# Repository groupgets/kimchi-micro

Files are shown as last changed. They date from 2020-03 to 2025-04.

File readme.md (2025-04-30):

# kimχ micro

kimχ micro is a small and spicy open hardware embedded SBC that offers tons of
versitility for many different applications.

kimchi micro

## Work in progress

This board is still a work in progress and is not yet considered production-
ready. If you wish to build this hardware yourself, expect that there may still
be some bugs.

## Features

### Application Processor

This project was undertaken with video encoding/decoding and wireless
connectivity in mind, so the i.MX8M Mini variant supports 1080p60 hardware video
encode/decode.

### Mini PCIe

The board can host a half- or full-mini PCIe module as often used for high-power
wifi chipsets. Mini PCIe is also perfect for other types of wireless such as LTE
and LoRa radios.

### USB-C

The board has a full-featured USB-C port with power source and sink
capabilities, as well as support for battery charging and power.

### Expansion

To enable different applications, kimχ micro has high-density expansion
connectors and a standard add-on module specification, as well as a Qwiic
connector for rapid prototyping or simple sensor integration.

## FAQ

### How do I pronounce kimχ

Like the spicy fermented cabbage (kimchi)

### Why did you call it that

So that when we make more of these boards, we can name them things like
saurkraut, sarmale, or cole slaw, and have a series of them called the cabbage
patch. But we really do love kimchi, and it has part of KiCad in it, and i.MX.

## License

The source files for this project are licensed under CERN-OHL-S V.2. This means
you are free to reuse all or part of this design in your own projects, provided
these projects also carry the same license.

Important Note
============
GroupGets does not provide coding, firmware, or software support of any kind and will not respond to related requests. All software and firmware provided by GroupGets are offered solely as examples or potential starting points. These repositories may be outdated and are not guaranteed to function as intended.

We do not accept returns or offer replacements due to issues related to software, firmware, or code compatibility.

The software is provided "AS IS", without warranty of any kind, express or implied, including but not limited to the warranties of merchantability, fitness for a particular purpose and non-infringement. In no event shall the authors or copyright holders be liable for any claim, damages, or other liability, whether in an action of contract, tort, or otherwise, arising from, out of, or in connection with the software or the use or other dealings in the software.

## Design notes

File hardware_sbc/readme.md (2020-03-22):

# KiCAD board files for kimx micro

## Impedance requirements

```

All tolerances +/-10%.

Layers 1, 8 (kimchi_micro-F_Cu.gtl, kimchi_micro-B_Cu.gbl)
    Single ended:
        Width: 4.79 mils
        Impedance: 50 Ohms
    Differential:
        Width / Gap: 4.99 mils / 4 mils
        Impedance: 85 Ohms
    Differential:
        Width / Gap: 3.99 mils / 3.5 mils
        Impedance: 90 Ohms
    Differential:
        Width / Gap: 3.39 mils / 4.1 mils
        Impedance: 100 Ohms

Layers 2-4 (kimchi_micro-In[2-4]_Cu.g[2-4])
    Single ended:
        Width: 3.59 mils
        Impedance:  50 Ohms

```

## Stackup

```

Copper     FCu  -----                           0.33 oz, plating to 1oz
PP              xxxxx   3 mil
FR4      L2/L3  =====   0.1 mm (except copper)  1/1 oz
PP              xxxxx   9.3 mil
FR4      L4/L5  =====   0.1 mm (except copper)  1/1 oz
PP              xxxxx   9.3 mil
FR4      L6/L7  =====   0.1 mm (except copper)  1/1 oz
PP              xxxxx   3 mil
Copper     BCu  -----                           0.33 oz, plating to 1oz

Lamination thickness: 1.11 mm +/- 0.08 mm
Finished thickness: 1.2 mm

```

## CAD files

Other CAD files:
hardware_sbc/production/kimchi_micro.step

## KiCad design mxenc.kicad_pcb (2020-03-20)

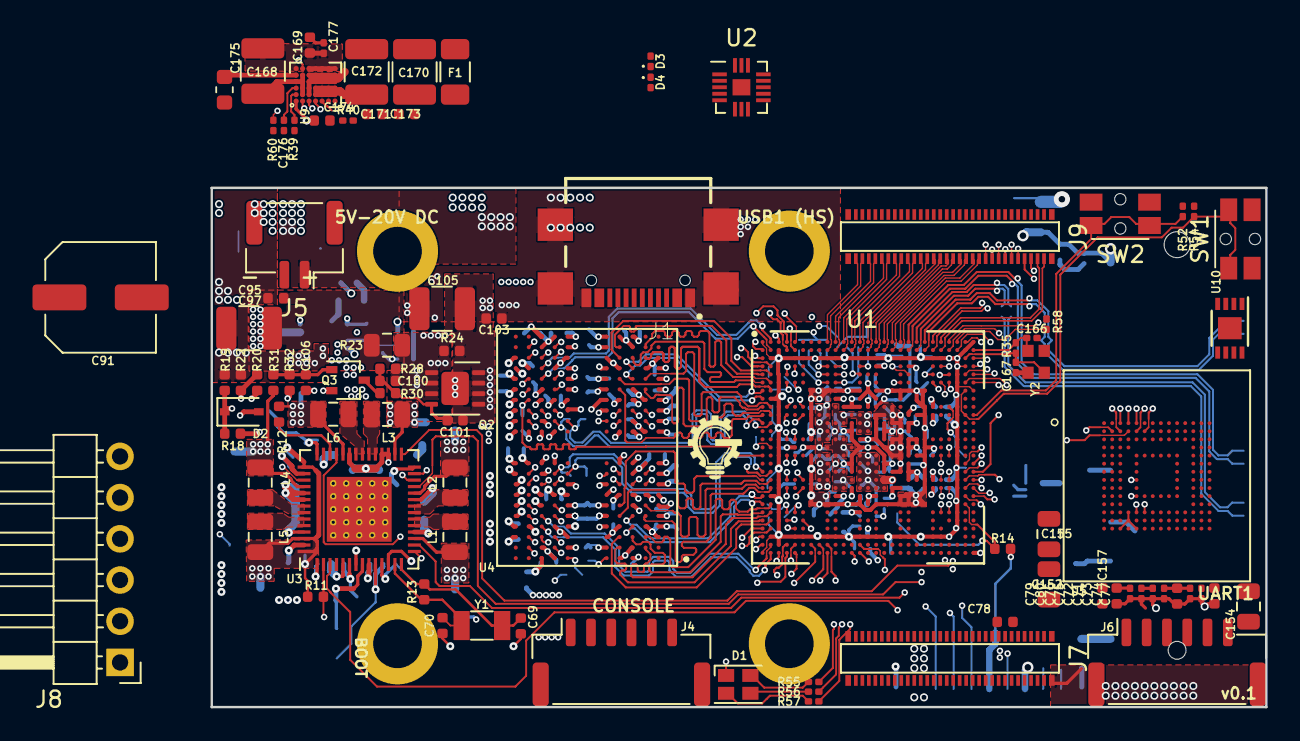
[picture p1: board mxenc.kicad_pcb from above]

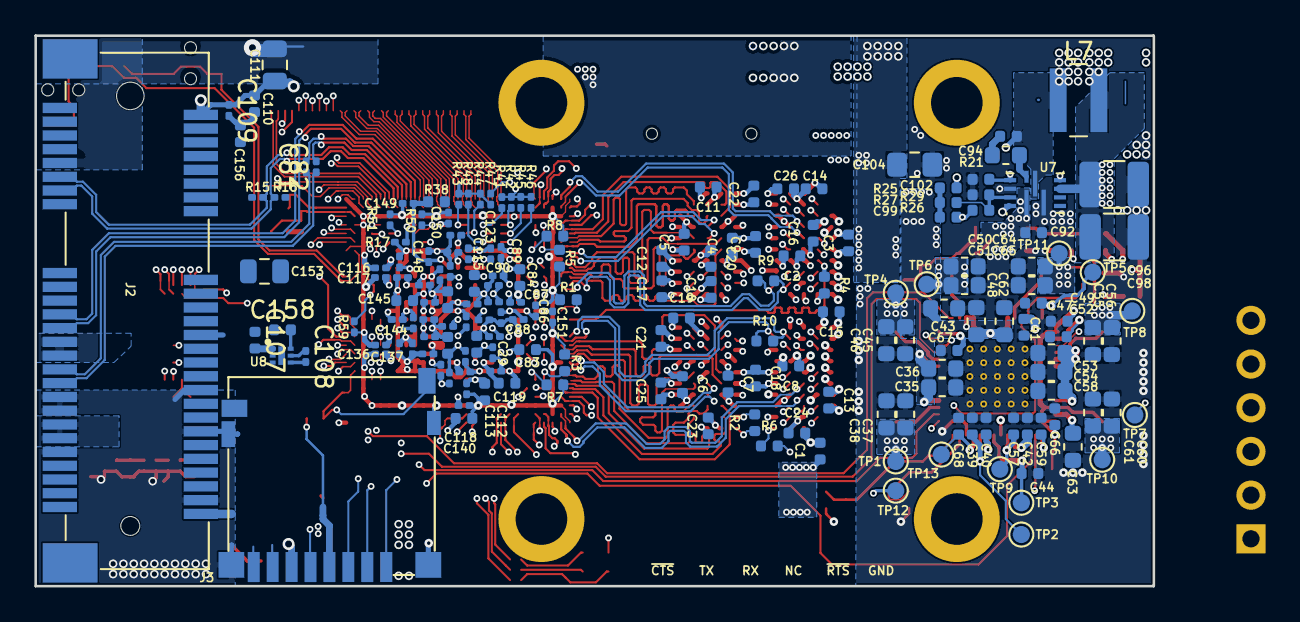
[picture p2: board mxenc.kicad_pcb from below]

Board: 8 copper layers, 65.0 x 32.0 mm, 273 parts (181 on the bottom side), 222 nets.

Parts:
C1, C2, C3, C4, C9, C10, C11, C12, C18, C19, C20, C21, C27, C28, C77, C83, C84, C112, C124, C130, C140, C157: 10uF; C_0402_1005Metric
C5, C6, C7, C8, C13, C14, C15, C16, C17, C22, C23, C24, C25, C26, C78, C94, C100, C101: 0.22uF; C_0402_1005Metric
C29, C30, C31, C32, C33, C34, C85, C86, C87, C88, C89, C90, C116, C125, C126, C127, C128, C129, C131, C132, C133, C134, C135, C151: 1uF; C_0201_0603Metric
C35, C36, C43, C48, C53, C54, C58, C62: 10uF; C_0603_1608Metric
C37, C38, C45, C46, C50, C51, C55, C56, C60, C61, C64, C65: 22uF; C_0603_1608Metric
C39, C44, C47, C52, C57, C67, C68, C79, C102, C103, C158: 1uF; C_0402_1005Metric
C40, C41, C42, C107: 2.2uF; C_0402_1005Metric
C49, C59, C66, C71, C110, C119, C145, C156: 4.7uF; C_0402_1005Metric
C63: 1uF; C_0603_1608Metric
C69, C70: 18pF; C_0402_1005Metric
C72, C73, C74, C75, C76, C80, C113, C114, C115, C117, C118, C120, C121, C122, C123, C136, C137, C138, C139, C141, C142, C143, C144, C146, C147, C148: 0.22uF; C_0201_0603Metric
C81, C82, C108, C109: 0.1uF; C_0201_0603Metric
C91: 100uF; C_Elec_6.3x5.8
C92, C95, C106, C169, C171, C173, C174: 0.1uF; C_0402_1005Metric
C96, C97, C98, C105: 100uF; C_1210_3225Metric
C99: DNP; C_0402_1005Metric
C104: 10uF; C_0805_2012Metric_Pad1.15x1.40mm_HandSolder
C111, C152, C153, C154, C155: 47uF; C_0805_2012Metric
C149: 2.2uF; C_0201_0603Metric
C150: 2200pF; C_0201_0603Metric
C166, C167: 12pF; C_0201_0603Metric
C168, C172: 47uF; C_1210_3225Metric
C170: 4.7uF; C_1210_3225Metric
C175: 4.7uF; C_0603_1608Metric
C176: 0.01uF; C_0201_0603Metric
C177: 1000pF; C_0201_0603Metric
D1: LED_ARGB; LED_Cree-PLCC4_2x2mm_CW
D2: D_Zener; D_SOD-323
D3, D4: D_TVS; D_0201_0603Metric
F1: Polyfuse; C_1206_3216Metric
J1: USB_C_Receptacle; GCT_USB4110-GF-A
J2: Bus_PCI_Express_Mini; 1775838-2-NPTH
J3: Micro_SD_Card; 114-00841-68
J4, J6: Conn_01x06; JST_GH_SM06B-GHS-TB_1x06-1MP_P1.25mm_Horizontal
J5: Conn_01x02; JST_GH_SM02B-GHS-TB_1x02-1MP_P1.25mm_Horizontal
J7, J9: DF40HC(3.5)-60DS; DF40C-60DP
J8: Conn_01x06 DNP; PinHeader_1x06_P2.54mm_Horizontal
L1, L2, L3, L5, L6: 0.47uH; L_0806
L4: 1uH; L_0806
L7: 1.5uH; L_Wuerth_MAPI-4020
L8: GG_LOGO; gg-4x4
Q2: AON7405; DFN-8-1EP_3x3mm_P0.65mm_EP1.7x2.05mm
Q3: Q_NMOS_GSD; SOT-323_SC-70
R1, R2, R6: 240; R_0402_1005Metric
R3, R5, R7, R8: 10K DNP; R_0402_1005Metric
R4, R14: 10K; R_0402_1005Metric
R9, R10: 150; R_0402_1005Metric
R11, R12, R20, R22, R32: 100K; R_0402_1005Metric
R13: 1M DNP; R_0402_1005Metric
R15, R16: 49.9; R_0201_0603Metric
R17: 8.2K; R_0201_0603Metric
R18: 1K; R_0402_1005Metric
R19, R24, R27: DNP; R_0402_1005Metric
R21: 3.3; R_0603_1608Metric
R23: 0; R_0805_2012Metric
R25: 499K DNP; R_0402_1005Metric
R26: 41.2K; R_0402_1005Metric
R28, R31: 22K; R_0402_1005Metric
R29: 5.6K; R_0402_1005Metric
R30: 4.7K; R_0402_1005Metric
R35: 510K; R_0201_0603Metric
R38: 0; R_0402_1005Metric
R39, R40, R59, R60: 100K; R_0201_0603Metric
R41, R42, R43, R44, R45, R46, R47, R48: 4.7K; R_0201_0603Metric
R50, R51: 200; R_0201_0603Metric
R52, R54, R58: 10K; R_0201_0603Metric
R55: 68; R_0201_0603Metric
R56, R57: 22; R_0201_0603Metric
SW1, SW2: SW_Push; SW_SPST_EVQP7C
TP1, TP2, TP3, TP4, TP5, TP6, TP7, TP8, TP9, TP10, TP11, TP12, TP13: TestPoint; TestPoint_Pad_D1.0mm
U1: IMX8MM; BGA-729_27x27_14.0x14.0mm
U2: PTN5110NHQZ; HX2QFN-16_EP_2.85x2.85_Pitch0.4mm
U3: BD71847MWV; QFN-56_EP_7x7_Pitch0.4mm
U4: MT53E256M32D2DS-053 WT:B; BGA200C80X65P12X22_1100X1450X80N
U5: SDINBDG4-8G; BGA153C50P14X14_1300X1150X80N
U7: MP8759GD; QFN-16_2x3_Pitch0.5mm
U8: NCP133AMX150TCG; XDFN6_1.20x1.20_0.40P
U9: NX20P3483UK; BGA-42_6x7_2.51x2.91mm
U10: 24LC16; DFN-8-1EP_3x2mm_P0.5mm_EP1.36x1.46mm
Y1: Crystal; Crystal_SMD_3215-2Pin_3.2x1.5mm
Y2: Crystal_GND24; XRCGB

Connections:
/CLK_32K: U1.A26, U3.29
/CPU Power/VDD_MIPI_1P2: C148.1, C149.1, R38.2, U1.J15
/DRAM/DRAM_CA0_A: U1.J6, U4.R2
/DRAM/DRAM_CA0_B: U1.W6, U4.H2
/DRAM/DRAM_CA1_A: U1.K6, U4.P2
/DRAM/DRAM_CA1_B: U1.V6, U4.J2
/DRAM/DRAM_CA2_A: U1.E4, U4.R9
/DRAM/DRAM_CA2_B: U1.AC4, U4.H9
/DRAM/DRAM_CA3_A: U1.D5, U4.R10
/DRAM/DRAM_CA3_B: U1.AD5, U4.H10
/DRAM/DRAM_CA4_A: U1.N4, U4.R11
/DRAM/DRAM_CA4_B: U1.R4, U4.H11
/DRAM/DRAM_CA5_A: U1.N5, U4.P11
/DRAM/DRAM_CA5_B: U1.R5, U4.J11
/DRAM/DRAM_CKE0_A: R5.1, U1.F4, U4.P4
/DRAM/DRAM_CKE0_B: R3.1, U1.AB4, U4.J4
/DRAM/DRAM_CKE1_A: R8.1, U1.F5, U4.P5
/DRAM/DRAM_CKE1_B: R7.1, U1.AB5, U4.J5
/DRAM/DRAM_CK_A_N: R9.2, U1.L1, U4.P9
/DRAM/DRAM_CK_A_P: R9.1, U1.L2, U4.P8
/DRAM/DRAM_CK_B_N: R10.2, U1.U1, U4.J9
/DRAM/DRAM_CK_B_P: R10.1, U1.U2, U4.J8
/DRAM/DRAM_CS0_A: U1.K4, U4.R4
/DRAM/DRAM_CS0_B: U1.V4, U4.H4
/DRAM/DRAM_CS1_A: U1.J4, U4.R3
/DRAM/DRAM_CS1_B: U1.W4, U4.H3
/DRAM/DRAM_DATA0_A: U1.A5, U4.AA11
/DRAM/DRAM_DATA0_B: U1.AB2, U4.B2
/DRAM/DRAM_DATA1_A: U1.B5, U4.Y11
/DRAM/DRAM_DATA1_B: U1.AA2, U4.C2
/DRAM/DRAM_DATA2_A: U1.D2, U4.V11
/DRAM/DRAM_DATA2_B: U1.W1, U4.F2
/DRAM/DRAM_DATA3_A: U1.D1, U4.U11
/DRAM/DRAM_DATA3_B: U1.W2, U4.E2
/DRAM/DRAM_DATA4_A: U1.C1, U4.U9
/DRAM/DRAM_DATA4_B: U1.V2, U4.E4
/DRAM/DRAM_DATA5_A: U1.B1, U4.V9
/DRAM/DRAM_DATA5_B: U1.V1, U4.F4
/DRAM/DRAM_DATA6_A: U1.A3, U4.Y9
/DRAM/DRAM_DATA6_B: U1.AC1, U4.B4
/DRAM/DRAM_DATA7_A: U1.B4, U4.AA9
/DRAM/DRAM_DATA7_B: U1.AC2, U4.C4
/DRAM/DRAM_DATA8_A: U1.F2, U4.AA2
/DRAM/DRAM_DATA8_B: U1.AG5, U4.B11
/DRAM/DRAM_DATA9_A: U1.G2, U4.Y2
/DRAM/DRAM_DATA9_B: U1.AF5, U4.C11
/DRAM/DRAM_DATA10_A: U1.J1, U4.V4
/DRAM/DRAM_DATA10_B: U1.AD2, U4.E11
/DRAM/DRAM_DATA11_A: U1.J2, U4.V2
/DRAM/DRAM_DATA11_B: U1.AD1, U4.F11
/DRAM/DRAM_DATA12_A: U1.K2, U4.U2
/DRAM/DRAM_DATA12_B: U1.AE1, U4.F9
/DRAM/DRAM_DATA13_A: U1.K1, U4.U4
/DRAM/DRAM_DATA13_B: U1.AF1, U4.E9
/DRAM/DRAM_DATA14_A: U1.E1, U4.AA4
/DRAM/DRAM_DATA14_B: U1.AG3, U4.C9
/DRAM/DRAM_DATA15_A: U1.E2, U4.Y4
/DRAM/DRAM_DATA15_B: U1.AF4, U4.B9
/DRAM/DRAM_DMI0_A: U1.A4, U4.Y10
/DRAM/DRAM_DMI0_B: U1.AB1, U4.C3
/DRAM/DRAM_DMI1_A: U1.F1, U4.Y3
/DRAM/DRAM_DMI1_B: U1.AG4, U4.C10
/DRAM/DRAM_NRESET: R4.1, U1.R1, U4.T11
/DRAM/DRAM_SDQS0_A_N: U1.B2, U4.V10
/DRAM/DRAM_SDQS0_A_P: U1.A2, U4.W10
/DRAM/DRAM_SDQS0_B_N: U1.Y1, U4.E3
/DRAM/DRAM_SDQS0_B_P: U1.AA1, U4.D3
/DRAM/DRAM_SDQS1_A_N: U1.H1, U4.V3
/DRAM/DRAM_SDQS1_A_P: U1.G1, U4.W3
/DRAM/DRAM_SDQS1_B_N: U1.AF2, U4.E10
/DRAM/DRAM_SDQS1_B_P: U1.AG2, U4.D10
/DRAM/DRAM_ZQ0: R2.1, U4.A5
/DRAM/DRAM_ZQ1: R6.1, U4.A8
/Expansion/CAM_CK_N: J9.45, U1.A16
/Expansion/CAM_CK_P: J9.46, U1.B16
/Expansion/CAM_D0_N: J9.41, U1.A14
/Expansion/CAM_D0_P: J9.42, U1.B14
/Expansion/CAM_D1_N: J9.43, U1.A15
/Expansion/CAM_D1_P: J9.44, U1.B15
/Expansion/CAM_D2_N: J9.47, U1.A17
/Expansion/CAM_D2_P: J9.48, U1.B17
/Expansion/CAM_D3_N: J9.49, U1.A18
/Expansion/CAM_D3_P: J9.50, U1.B18
/Expansion/DISP_CK_N: J9.35, U1.A11
/Expansion/DISP_CK_P: J9.36, U1.B11
/Expansion/DISP_D0_N: J9.31, U1.A9
/Expansion/DISP_D0_P: J9.32, U1.B9
/Expansion/DISP_D1_N: J9.33, U1.A10
/Expansion/DISP_D1_P: J9.34, U1.B10
/Expansion/DISP_D2_N: J9.37, U1.A12
/Expansion/DISP_D2_P: J9.38, U1.B12
/Expansion/DISP_D3_N: J9.39, U1.A13
/Expansion/DISP_D3_P: J9.40, U1.B13
/I2C1_SCL: R45.2, U1.E9, U3.26
/I2C1_SDA: R46.2, U1.F9, U3.27
/I2C2_SCL: R41.2, U1.D10, U10.6
/I2C2_SDA: R42.2, U1.D9, U10.5
/I2C3_SCL: J2.30, R47.2, U1.E10, U9.B1
/I2C3_SDA: J2.32, R48.2, U1.F10, U9.C1
/I2C4_SCL: R43.2, U1.D13
/I2C4_SDA: R44.2, U1.E13
/LD1_~INT: U1.F18, U9.D1
/LED_B: R57.1, U1.AF9
/LED_G: R56.1, U1.AG9
/LED_R: R55.1, U1.AF8
/PCIE_DISB: J2.20, U1.AG16
/PCIE_RSTB: J2.22, U1.AF16
/PCIe/PCIE_CLK_N: J2.11, R15.2, U1.A21
/PCIe/PCIE_CLK_P: J2.13, R16.2, U1.B21
/PCIe/PCIE_RXN_N: J2.23, U1.A19
/PCIe/PCIE_RXN_P: J2.25, U1.B19
/PCIe/PCIE_TXN_1_N: C81.2, U1.A20
/PCIe/PCIE_TXN_1_P: C82.2, U1.B20
/PCIe/PCIE_TXN_N: C81.1, J2.31
/PCIe/PCIE_TXN_P: C82.1, J2.33
/PMIC_ON_REQ: U1.A24, U3.15
/PMIC_STBY_REQ: U1.E24, U3.16
/PMIC_nINT: U1.AF13, U3.39
/POR_B: U1.B24, U3.25
/Power/BST: R21.2, U7.8
/Power/DCDC_5V_OUT: C95.1, C96.1, C97.1, C98.1, C99.1, L7.2, R23.2, R26.2, U7.5
/Power/EN: D2.1, R18.2, R19.1, U7.12
/Power/FB: R26.1, R27.2, R29.2, U7.11
/Power/MODE: R20.1, R22.1, U7.6
/Power/SW: C94.2, L7.1, R25.2, U7.7
/Power/VCC_3V6: C102.1, R20.2, U7.9
/RTC_RESET_B: U1.F24, U3.3
/SD2_VSEL: U1.AG12, U3.45
/SD/MMC/EMMC_CLK: U1.V26, U5.M6
/SD/MMC/EMMC_CMD: U1.V27, U5.M5
/SD/MMC/EMMC_DAT0: U1.Y27, U5.A3
/SD/MMC/EMMC_DAT1: U1.Y26, U5.A4
/SD/MMC/EMMC_DAT2: U1.T27, U5.A5
/SD/MMC/EMMC_DAT3: U1.T26, U5.B2
/SD/MMC/EMMC_DAT4: U1.U27, U5.B3
/SD/MMC/EMMC_DAT5: U1.U26, U5.B4
/SD/MMC/EMMC_DAT6: U1.W27, U5.B5
/SD/MMC/EMMC_DAT7: U1.W26, U5.B6
/SD/MMC/EMMC_RCLK: U1.R24, U5.H5
/SD/MMC/EMMC_RST: U1.R23, U5.K5
/SD/MMC/EMMC_VDDI: C79.1, C80.1, U5.C2
/SD/MMC/SD_CD: J3.10, R14.1, U1.AA26
/SD/MMC/SD_CLK: J3.5, U1.W23
/SD/MMC/SD_CMD: J3.3, U1.W24
/SD/MMC/SD_DAT0: J3.7, U1.AB23
/SD/MMC/SD_DAT1: J3.8, U1.AB24
/SD/MMC/SD_DAT2: J3.1, U1.V24
/SD/MMC/SD_DAT3: J3.2, U1.V23
/SYS_NRST: R12.1, U3.40
/UART1_CTS_B: J6.4, U1.AD23
/UART1_RTS_B: J6.5, U1.AC24
/UART1_RX: J6.2, U1.AB22
/UART1_TX: J6.3, U1.AC19
/UART2_CTS_B: J4.4, J8.6
/UART2_RTS_B: J4.5, J8.2
/UART2_RX: J4.2, J8.4, U1.F15
/UART2_TX: J4.3, J8.5, U1.E15
/USB/USB1_DN: D4.1, J1.A7, J1.B7, U1.A22
/USB/USB1_DP: D3.1, J1.A6, J1.B6, U1.B22
/USB/USB1_VBUS: F1.1, J1.A4, J1.A9, U1.F22
/USB/USB1_VBUS_F: C170.1, C171.1, F1.2, U9.C2, U9.C3, U9.C4, U9.C5, U9.D4, U9.D5, U9.E4, U9.E5, U9.F4, U9.F5, U9.G4, U9.G5
/VBUS_IN: C91.1, C92.1, C168.1, C169.1, C177.1, J5.1, R18.1, U7.1, U9.A6, U9.C6, U9.D6, U9.E6, U9.F6, U9.G6
/WDOG_B: R11.1, U1.AG13, U3.2
GND: C1.2, C2.2, C3.2, C4.2, C5.2, C6.2, C7.2, C8.2, C9.2, C10.2, C11.2, C12.2, C13.2, C14.2, C15.2, C16.2, C17.2, C18.2, C19.2, C20.2, C21.2, C22.2, C23.2, C24.2, C25.2, C26.2, C27.2, C28.2, C29.2, C30.2, C31.2, C32.2, C33.2, C34.2, C35.2, C36.2, C37.1, C38.1, C39.1, C40.2, C41.2, C42.2, C43.2, C44.1, C45.1, C46.1, C47.1, C48.2, C49.1, C50.1, C51.1, C52.1, C53.2, C54.2, C55.1, C56.1, C57.1, C58.2, C59.1, C60.1, C61.1, C62.2, C63.1, C64.1, C65.1, C66.1, C67.1, C68.2, C69.1, C70.1, C71.2, C72.2, C73.2, C74.2, C75.2, C76.2, C77.2, C78.2, C79.2, C80.2, C83.2, C84.2, C85.2, C86.2, C87.2, C88.2, C89.2, C90.2, C91.2, C92.2, C95.2, C96.2, C97.2, C98.2, C102.2, C103.2, C104.2, C105.2, C106.2, C107.1, C108.1, C109.2, C110.2, C111.2, C112.2, C113.2, C114.2, C115.2, C116.1, C117.1, C118.1, C119.2, C120.2, C121.2, C122.2, C123.2, C124.2, C125.2, C126.2, C127.2, C128.2, C129.2, C130.2, C131.2, C132.2, C133.2, C134.2, C135.2, C136.2, C137.2, C138.2, C139.2, C140.2, C141.2, C142.2, C143.2, C144.2, C145.2, C146.2, C147.2, C148.2, C149.2, C150.2, C151.2, C152.2, C153.2, C154.2, C155.2, C156.2, C157.2, C158.1, C166.2, C167.2, C168.2, C169.2, C170.2, C171.2, C172.2, C173.2, C174.2, C175.2, C176.2, C177.2, D2.2, D3.2, D4.2, J1.A1, J1.A12, J1.S1, J2.4, J2.9, J2.15, J2.18, J2.21, J2.26, J2.27, J2.29, J2.34, J2.35, J2.37, J2.40, J2.43, J2.50, J3.6, J3.9, J3.11, J4.6, J5.2, J6.6, J7.MP, J8.1, J9.MP, Q3.2, R1.2, R3.2, R4.2, R5.2, R7.2, R8.2, R15.1, R16.1, R17.2, R19.2, R22.2, R29.1, R32.1, R39.2, R40.2, R50.2, R51.2, R52.1, R54.1, R59.2, R60.2, U1.A1, U1.A27, U1.AA7, U1.AA9, U1.AA10, U1.AA13, U1.AA15, U1.AA18, U1.AA19, U1.AA21, U1.AB3, U1.AB25, U1.AC3, U1.AC25, U1.AE2, U1.AE5, U1.AE6, U1.AE9, U1.AE10, U1.AE13, U1.AE14, U1.AE15, U1.AE18, U1.AE19, U1.AE22, U1.AE23, U1.AF3, U1.AG1, U1.AG27, U1.B3, U1.B26, U1.C2, U1.C5, U1.C6, U1.C9, U1.C10, U1.C13, U1.C14, U1.C15, U1.C18, U1.C19, U1.C22, U1.C23, U1.D26, U1.E3, U1.E25, U1.F3, U1.F25, U1.G7, U1.G9, U1.G10, U1.G13, U1.G15, U1.G18, U1.G19, U1.G21, U1.G27, U1.H2, U1.H18, U1.J3, U1.J7, U1.J21, U1.J25, U1.K3, U1.K7, U1.K20, U1.K21, U1.K25, U1.L12, U1.L16, U1.M12, U1.M16, U1.N3, U1.N7, U1.N12, U1.N16, U1.N21, U1.N25, U1.P3, U1.P13, U1.P15, U1.P21, U1.P25, U1.R3, U1.R7, U1.R12, U1.R16, U1.R20, U1.R21, U1.R25, U1.T12, U1.T16, U1.U12, U1.U16, U1.V3, U1.V7, U1.V21, U1.V25, U1.W3, U1.W7, U1.W21, U1.W25, U1.Y2, U1.Y13, U1.Y18, U3.12, U3.57, U4.A3, U4.A10, U4.AB3, U4.AB5, U4.AB8, U4.AB10, U4.C1, U4.C5, U4.C8, U4.C12, U4.D2, U4.D4, U4.D9, U4.D11, U4.E1, U4.E5, U4.E8, U4.E12, U4.G1, U4.G3, U4.G5, U4.G8, U4.G10, U4.G12, U4.J1, U4.J3, U4.J10, U4.J12, U4.K2, U4.K4, U4.K9, U4.K11, U4.N2, U4.N4, U4.N9, U4.N11, U4.P1, U4.P3, U4.P10, U4.P12, U4.T1, U4.T3, U4.T5, U4.T8, U4.T10, U4.T12, U4.V1, U4.V5, U4.V8, U4.V12, U4.W2, U4.W4, U4.W9, U4.W11, U4.Y1, U4.Y5, U4.Y8, U4.Y12, U5.A6, U5.C4, U5.E7, U5.G5, U5.H10, U5.J5, U5.K8, U5.N2, U5.N5, U5.P4, U5.P6, U7.2, U7.10, U8.5, U8.7, U9.A4, U9.B2, U9.B3, U9.B4, U9.B5, U10.4, U10.7, Y2.2, Y2.4
GPIO3[5]: R52.2, SW2.1, U1.K27
GPIO3[12]: R54.2, SW1.1, U1.G26, U1.K26
JTAG_MOD: J9.51, U1.D27
JTAG_TCK: J9.56, U1.F26
JTAG_TDI: J9.54, U1.E27
JTAG_TDO: J9.53, U1.E26
JTAG_TMS: J9.55, U1.F27
JTAG_TRST_B: J9.52, U1.C27
NVCC_1V8: C1.1, C2.1, C3.1, C4.1, C5.1, C6.1, C7.1, C8.1, C49.2, C60.2, C61.2, C66.2, C74.1, C75.1, C76.1, C77.1, C112.1, C113.1, C114.1, C115.1, C136.1, C138.1, C139.1, C158.2, L5.2, R11.2, R41.1, R42.1, R45.1, R46.1, SW1.2, SW2.2, TP10.1, U1.AB13, U1.J11, U1.J12, U1.J13, U1.L19, U1.M19, U1.T19, U1.U19, U1.V19, U1.V20, U1.W12, U1.W22, U3.43, U3.54, U3.56, U4.F1, U4.F12, U4.G4, U4.G9, U4.T4, U4.T9, U4.U1, U4.U12, U5.C6, U5.M4, U5.N4, U5.P3, U5.P5, U8.3, U8.6, U10.8
NVCC_3V3: C55.2, C56.2, C59.2, C71.1, C72.1, C73.1, C108.2, C109.1, C110.1, C111.1, C119.1, C120.1, C121.1, C122.1, C123.1, C152.1, C153.1, C154.1, C155.1, C174.1, D1.1, J2.2, J2.24, J2.39, J2.41, J2.52, L4.2, R31.1, R43.1, R44.1, R47.1, R48.1, TP8.1, U1.H10, U1.K19, U1.W17, U1.W18, U1.Y10, U3.1, U3.7, U3.46, U5.E6, U5.F5, U5.J10, U5.K9, U8.4, U9.A1
NVCC_DRAM_1V1: C9.1, C10.1, C11.1, C12.1, C13.1, C14.1, C15.1, C16.1, C17.1, C18.1, C19.1, C20.1, C21.1, C22.1, C23.1, C24.1, C25.1, C26.1, C64.2, C65.2, C83.1, C84.1, C85.1, C86.1, C87.1, C88.1, C89.1, C90.1, L6.2, R2.2, R6.2, R12.2, TP11.1, U1.K8, U1.K9, U1.L9, U1.M9, U1.N8, U1.N9, U1.P7, U1.R8, U1.R9, U1.T9, U1.U9, U1.V8, U1.V9, U3.38, U4.A4, U4.A9, U4.AA3, U4.AA5, U4.AA8, U4.AA10, U4.AB4, U4.AB9, U4.B3, U4.B5, U4.B8, U4.B10, U4.D1, U4.D5, U4.D8, U4.D12, U4.F3, U4.F5, U4.F8, U4.F10, U4.G2, U4.H1, U4.H5, U4.H8, U4.H12, U4.K1, U4.K3, U4.K10, U4.K12, U4.N1, U4.N3, U4.N10, U4.N12, U4.R1, U4.R5, U4.R8, U4.R12, U4.T2, U4.U3, U4.U5, U4.U8, U4.U10, U4.W1, U4.W5, U4.W8, U4.W12
NVCC_SD2: C63.2, C78.1, C137.1, J3.4, R14.2, TP12.1, U1.V22, U3.55
NVCC_SNVS_1V8: C39.2, C67.2, C116.2, R58.2, TP2.1, U1.J22, U3.10, U3.28
unnamed: C68.1, TP13.1, U3.11
unnamed: C69.2, R13.2, U3.14, Y1.1
unnamed: C70.2, R13.1, U3.13, Y1.2
unnamed: C94.1, R21.1
unnamed: C99.2, R25.1, R27.1
unnamed: C100.1, C101.2, Q2.4, R28.1, R30.2
unnamed: C106.1, Q3.1, R31.2, R32.2
unnamed: C150.1, U1.D15
unnamed: C166.1, R35.2, U1.B27, Y2.1
unnamed: C167.1, R35.1, U1.C26, Y2.3
unnamed: C175.1, U9.A5
unnamed: C176.1, U9.A3
unnamed: D1.2, R55.2
unnamed: D1.3, R56.2
unnamed: D1.4, R57.2
unnamed: L1.1, U3.19, U3.20
unnamed: L2.1, U3.21, U3.22
unnamed: L3.1, U3.33, U3.34
unnamed: L4.1, U3.49, U3.50
unnamed: L5.1, U3.51, U3.52
unnamed: L6.1, U3.35, U3.36
unnamed: Q3.3, R30.1
unnamed: R1.1, U1.P2
unnamed: R17.1, U1.D19
unnamed: R39.1, U9.A2
unnamed: R40.1, U9.E1
unnamed: R50.1, U1.E19
unnamed: R51.1, U1.E22
unnamed: R58.1, U1.A25
unnamed: R59.1, U1.J24
unnamed: R60.1, U9.B6
USB2_DN: J9.59, U1.A23
USB2_DP: J9.60, U1.B23
USB2_ID: J9.58, U1.D23
USB2_VBUS: J9.57, U1.F23
VDDA_1V8: C57.2, C118.2, C140.1, C141.1, C142.1, C143.1, C144.1, C151.1, TP9.1, U1.AA14, U1.G14, U1.H13, U1.H15, U1.N19, U1.N20, U1.P5, U1.P19, U1.R19, U1.Y15, U3.6
VDD_5V: C101.1, C103.1, C104.1, C105.1, C172.1, C173.1, J4.1, J6.1, Q2.5, Q2.6, Q2.7, Q2.8, Q2.9, R24.1, U9.D2, U9.D3, U9.E2, U9.E3, U9.F2, U9.F3, U9.G2, U9.G3
VDD_ARM_0V9: C45.2, C46.2, C124.1, C125.1, C126.1, C127.1, C128.1, C129.1, L2.2, TP4.1, U1.R13, U1.R15, U1.T13, U1.T14, U1.T15, U1.U13, U1.U15, U1.V13, U1.V15, U1.V16, U1.W13, U1.W14, U1.W15, U1.W16, U3.24
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

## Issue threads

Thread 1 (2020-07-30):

v0.9 errata

kekiefer, 2020-07-30:
This issue will be updated for any hardware bugs found in development of v0.9 board

* Problem: 1.8v-capable SDHC (UHS-I and newer) cards won't work in Linux
    Root cause: microsd SD2 powered by NVCC_SD2, but needs a constant 3.3V
    Workaround (software): add device tree property `no-1-8-v`
    Proposed v1.0 solution: supply microsd SD2 VDD with VDD_3V3

* Problem: voltage sag on initial power causes pmic to shut down
    Root cause: excessive inrush current on VDD_3V3 due to aggressive decoupling for PCIe
    Workaround (hardware): don't stuff C125-127. Change reflected in released v0.9 BOM.
    Proposed v1.0 solution: add load switch with inrush-limiting for PCIe 3.3V rail

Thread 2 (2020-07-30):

1.8v-capable SDHC (UHS-I and newer) cards won't work in Linux

kekiefer, 2020-07-30:
The switch to 1.8V operation for UHS-I mode is undervolting most cards, causing errors in operation.

J10 VDD should be supplied by VDD_3V3.

Closed 2020-07-30.

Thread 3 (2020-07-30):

voltage sag on initial power causes pmic to shut down

kekiefer, 2020-07-30:
Excessive inrush current due to aggressive decoupling on PCIe 3V3 is causing this voltage sag.

Removing these extra decoupling caps allows the pmic to power up properly.

kekiefer, 2020-07-30:
Fixed in 898216086c9d1b7934d0dd7573267c3b1b6184aa (BOM update)

Closed 2020-07-30.

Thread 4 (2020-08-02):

Type-C port will not take host role

kekiefer, 2020-08-02:
Type-C port controller PTN5110 (U9) not showing up in i2cdetect. This part should be located at 0x50 on i2c3, but does not show up in a scan:

```
root@kimchi:~# i2cdetect -y 3
     0  1  2  3  4  5  6  7  8  9  a  b  c  d  e  f
00:          -- -- -- -- -- -- -- -- -- -- -- -- --
10: -- -- -- -- -- -- -- -- -- -- -- -- -- -- -- --
20: -- -- -- -- -- -- -- -- -- -- -- -- UU -- -- --
30: -- -- -- -- -- -- -- -- -- -- -- -- -- -- -- --
40: -- -- -- -- -- -- -- -- -- -- -- -- -- -- -- --
50: -- -- -- -- -- -- -- 57 -- -- -- -- -- -- -- --
60: -- -- -- -- -- -- -- -- -- -- -- -- -- -- -- --
70: -- -- -- -- -- -- -- --                 
```

kekiefer, 2020-08-02:
Pins 7 and 8 (SDA/SCL) are swapped on the schematic.

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

Fix by cut and jump to pull up resistors R19/R20

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

Closed 2020-08-02.

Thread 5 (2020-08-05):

U12 pin BIN shorts to Vss against advisement of datasheet

kekiefer, 2020-08-05:
According to the BQ27426 datasheet:

> NOTE: The BIN pin must not be shorted directly to VCC or VSS and any pullup resistor on the BIN pin must be connected only to VDD and not an external voltage rail. If an external thermistor is used for temperature input, the thermistor should be connected between this pin and VSS.

When a pack is used with the board, the BIN FET Q1 is turned on, shorting BIN to VSS

kekiefer, 2020-08-05:
Rework to fix:

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

Future versions of the board should not include Q1, and pull BIN to VSS with 10K.

Closed 2020-08-05.

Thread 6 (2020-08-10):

Battery over discharge protection circuit does not work

kekiefer, 2020-08-10:
Leaving a battery pack that does not have internal over discharge protection results in a flat pack overnight.

Closed 2020-09-04.

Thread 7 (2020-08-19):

Certain high-power mPCIE wireless cards will not fit

kekiefer, 2020-08-19:
At least one high-power wireless card (Compex WLE1216V5-20) has components that extend beyond the vertical keepout area defined in the mPCIE specification. It will not fit without interfering with components on the board.

kekiefer, 2020-08-20:
The TE mPCIE connector has a taller version in the series, switching from 1775838-2 (5.6mm total height) to 2041262-1 (6.8mm total height) will be more accommodating.

Closed 2020-08-20.

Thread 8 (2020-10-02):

BGA inspection difficult for U12

gregdavill, 2020-10-02:
## Issue

`U12` is a 1.6mm x 1.6mm WLCSP with a 3x3 BGA array underneath. If assembly houses want to make use of x-ray inspection it may be difficult, because there is a large power inductor `L8` directly opposed, which casts a large shadow.

This may be a non-issue, but just something I stumbled across when inspecting my board after assembly.

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

kekiefer, 2020-10-02:
Thanks, good point. I should be able to move U12 down enough to make it visible. I really don't like anything about that huge inductor or where it is.

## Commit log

2020-03-20 re-layout power input switcher
    [USB.sch, power.sch]
2020-03-20 Improve bypass capacitor placement around dram and processor
2020-03-20 give emmc a more solid connection to power and ground
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2020-03-20 Add zener instead of fet to limit voltage on power input EN
    [CPU-power.sch, CSI.sch, DRAM.sch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]
2020-03-20 isolated vout a bit more from sw on power input, and better vin connection
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2020-03-20 improved 5v power supply routing
    [power.sch]
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2020-03-20 Tie boot0 to btn0 / sw1
    [mxenc.sch]
2020-03-20 Improve ground returns for ls and hs imx clocks, improve decoupling for usb-c mux
2020-03-20 Fix link to local footprint library
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2020-03-20 Add esd protection for usb
    [SD_MMC.sch, USB.sch, mxenc.sch]
2020-03-20 Re-add gg logo
    [mxenc.sch]
2020-03-20 Plot gerbers for v0.1 board
    [mxenc-B_Cu.gbl, mxenc-B_Mask.gbs, mxenc-B_Paste.gbp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]
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2020-03-20 wip more new layout
    [CPU-power.sch, CSI.sch, DRAM.sch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]
2020-03-20 rough layout, routing for emmc and csi, dsi, pcie
    [SD_MMC.sch, mxenc.kicad_pcb, mxenc.sch]
2020-03-20 More new layout, buttons, and routing
    [expansion.sch, mxenc.kicad_pcb, mxenc.sch]
2020-03-20 Complete entry of bom
    [CPU-power.sch, CSI.sch, DRAM.sch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]
2020-03-20 rerouted sd, added some gpio, started power input
    [expansion.sch, power.sch]
2020-03-20 add stencil jig sources
    [stencil-front.scad, stencil.scad]
2020-03-20 add sai, mdio, sdhc to headers
    [expansion.sch, mxenc.sch]
2020-03-20 Ground mounting pads and route ecspi to expansion
    [PCIe.sch, USB.sch, expansion.sch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]
2020-03-20 UIM and USB routing for PCIE to expansion
    [PCIe.sch, SD_MMC.sch, expansion.sch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]
2020-03-20 Finish remaining routing
    [CPU-power.sch, USB.sch, expansion.sch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]
2020-03-20 wip more uart routing
    [expansion.sch, mxenc.sch]
2020-03-20 prior to rerouting sai lanes
    [expansion.sch, mxenc.sch]
2020-03-20 Change expansion audio routing to sai2/3
    [expansion.sch, mxenc.sch, power.sch]
2020-03-20 Add esd protection to cc lines
    [USB.sch, expansion.sch, mxenc.sch]
2020-03-20 Fix up main power supply decoupling
    [USB.sch, power.sch]
2020-03-20 Change power input to JST-PH
    [USB.sch, mxenc.sch, power.sch]
2020-03-20 Switch 5V buck for 1S battery charger boost
    [USB.sch, mxenc.sch, power.sch]
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2020-03-20 Added PicoSPOX battery connection option w/ NTC
    [power.sch]
2020-03-20 Add header for main power input
    [power.sch]
2020-03-20 Set up for battery NTC and add a power button
    [CPU-power.sch, CSI.sch, DRAM.sch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]
2020-03-20 Cleanup remaining DRC problems from schematic
    [CPU-power.sch, SD_MMC.sch, USB.sch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]
2020-03-20 Additional capacitance for PCIe to support high power modules
    [PCIe.sch]
2020-03-20 Added zener for tvs on pcie
    [PCIe.sch]
2020-03-20 Re-annotate schematics, add dnp field, and silkscreen cleanup
    [CPU-power.sch, DRAM.sch, PCIe.sch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]
2020-03-20 Split mounting holes from pcie and put them on the front side
    [PCIe.sch]
2020-03-20 Fixed a few comments related to component reference and make sure we're displaying dnp
    [DRAM.sch, PMIC.sch, power.sch]
2020-03-20 Simplify control of VDD_5V with load switch
    [power.sch]
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2020-03-20 Add license information to schematics
    [CPU-power.sch, CSI.sch, DRAM.sch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]
2020-03-20 Update project name to kimchi_micro
    [kimchi_micro.sch]
2020-03-21 Move sbc design files to subdirectory
    [CPU-power.sch, CSI.sch, DRAM.sch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]
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2020-03-22 Clean up bom and add config for KiBoM
    [DRAM.sch, USB.sch, power.sch]
2020-03-30 Add battery monitor and protection circuit
    [kimchi_micro.sch, power.sch]
2020-04-09 Add production files for v0.9
    [kimchi_micro-B_Cu.gbl, kimchi_micro-B_Mask.gbs, kimchi_micro-B_Paste.gbp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]
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2020-06-05 BOM and misc fixes for production of 0.9 boards
    [CPU-power.sch, DRAM.sch, PCIe.sch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]
2020-06-11 Don't stuff C125-127
    These 3x 220uF caps are pulling down the 3v3 at boot. We need a
    load switch in the next rev.
    [PCIe.sch, kimchi_micro_bom_0.9.csv, power.sch]
2020-08-11 Supply microsd with vdd_3v3 instead of nvcc_sd2
    Fixes #2
    [SD_MMC.sch]
2020-08-11 Correct swapped sda/scl on U9
    Fixes #4
    [SD_MMC.sch, USB.sch]
2020-08-11 Correct U12 BIN pin connection
    Fixes #5
    [power.sch]
2020-08-13 Add load switch and separate power for VDD_PCIE_3V3
    Fixes #3
    [PCIe.sch, USB.sch, kimchi_micro.sch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]
2020-08-13 DNP PCIE_3V3_EN pull-down
    This part has an internal 2M pulldown, so this is no needed, but
    could be useful for rework (if we want to use a different signal
    to turn this on, for example). Move things around a bit to make this
    possible.
    [PCIe.sch]
2020-08-20 Update front stencil fixture for 6.8 mm mPCIE
    [stencil-front.scad]
2020-08-20 Change mPCIe connector to taller 2041262-1
    Fixes #7
    [PCIe.sch, kimchi_micro_bom_0.9.csv]
2020-09-04 Add low-side FET to properly disconnect battery on fault
    What was done in v0.9 to disable charge/discharge by driving IO on
    the charger circuit didn't really work out. Further, it had no way
    of monitoring overcurrent during discharge.
    Add a FED on the low side of the pack that can be controlled by the
    protection circuit, since this is how it is supposed to work.
    Fixes #6
    [power.sch]
2020-09-04 Measure battery voltage for monitor at same place as charger
    There was a small offset between the two, so this is just a small
    optimization to keep them as close as possible.
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2020-09-04 Enable charging by default, remove processor control
    Having the charge enable hooked up to the processor was problematic
    when the pin is not configured. There's not a great case for needing
    to have the processor enable/disable charging, so just leave it
    enabled.
    [kimchi_micro.sch, power.sch]
2020-09-28 Fill in missing part numbers for bom
    [power.sch]
2020-09-28 Production files for v0.91
    [CPU-power.sch, CSI.sch, DRAM.sch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]
2021-02-21 Replace system and charger LEDs with smaller 0404 RGB LED
    [kimchi_micro.sch, power.sch]
2021-02-22 Move power button side of board with USB
    [kimchi_micro.sch]
2021-02-22 Remove standoffs from board and update 3d model
    [PCIe.sch]
2021-03-20 Add vbus to expansion connector and bugfix for battery cutoff
    This will allow lids to supply power to charge the battery.
    The battery cutoff circuit needs V- connected to pack ground, so
    this was also fixed.
    [expansion.sch, kimchi_micro.sch, power.sch]
2021-03-20 Change common 22uF part from 4V to 6.3V
    Most placements don't require 5V, but a few do. The 4V part is no
    longer stocking as well, and price is similar, so change all to
    6.3V version.
    [PMIC.sch, power.sch]
2021-03-20 Remove boost feedback resistor R42
    This part was added in error, take it out
    [power.sch]
2021-03-20 Fixes for battery cutoff circuit (again)
    The DOUT side is supposed to be connected to the battery, and COUT
    to the board facing side. This is now correct.
    [power.sch]
2021-06-22 Reduced numerous 3d model sizes and fixups for KiCadStepUp
    No changes to board
2021-06-23 Production output for 0.92 and updated lid template
    [kimchi_micro-B_Cu.gbl, kimchi_micro-B_Mask.gbs, kimchi_micro-B_Paste.gbp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]
2025-10-27 Updating to KiCAD 8 and part number updates
    ## Schematic
    Part number updates
    - R41 changed from "RC0201FR-0778R7L" to "RMCF0201FT78K7"
    - R71, R72 changed from "RC0201JR-071ML" to "RC0201JR-075M1L"
    - U10, U13 alternate PN "NCP339BFCT2G" added
    ## PCB
    Design Rule Constraints
    - Copper Minimum clearance changed from 0 to 3 mils
    - Minimum thermal relief spoke count changed from 2 to 1
    - Solder mask aperture bridges items with different nets changed from Error to Warning
    - Silkscreen Minimum text height changed from 0.8mm to 0.5mm
    Cleaned up unconnected ends.
    Removed PMIC_ON_REQ via connected on only one layer.
    Removed redundant co-located drilled holes.
    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
    [CPU-power.kicad_sch, CSI.kicad_sch, DRAM.kicad_sch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]
2025-10-27 Moved buttons to allow for v-score panel
    R2 and R3 pulldown resistors moved to make space.
    U13 and J3 nudged as well.
2025-10-27 Updated production files and fixed schematic link issue.
    Fixed schematic unit number issue and re-linked to PCB.
    New gerbers, STEP file, schematic PDF.
    Deleted old KiCAD 6 files.
    [CPU-power.kicad_sch, CPU-power.sch, CSI.sch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]
2025-10-27 Updating board settings
    Reduced solder mask expansion to 1 mil and minimum web width to 6 mil.
2025-10-27 Updated production files
    Exported new production files, updated rev number and dates on schematic and PCB.
    [kimchi_micro-B_Cu.gbl, kimchi_micro-B_Mask.gbs, kimchi_micro-B_Paste.gbp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]
2025-10-27 Moved pwr silkscreen label
    pwr label was still at the old button location. Moved it across to the new location. Updated front silkscreen gerber layer.

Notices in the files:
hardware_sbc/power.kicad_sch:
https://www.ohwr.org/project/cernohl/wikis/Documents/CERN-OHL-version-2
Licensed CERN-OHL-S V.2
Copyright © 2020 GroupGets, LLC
